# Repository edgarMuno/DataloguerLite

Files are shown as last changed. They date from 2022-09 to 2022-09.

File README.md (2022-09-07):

# DataloguerLite
Dataloguer basico que soporta sensor de temperatura SHTX, sensor de humedad con protocolo RS485 RTU, sensor de humedad con protocolo SDI-12, puerto analogico, puerto para conexion de actuador. El sistema de monitoreo se le puede configurar el intervalo de medicion, el URL de Ubidots, APN, Direccion de sensores, Numero de sensores y el tipo de sensores mediante la memoria SD. El sistema se alimenta con un panel solar y baterias, y trasmite mediante un modulo GPRS los datos a la pltaforma UBIDOTS para la vizulaizacion.

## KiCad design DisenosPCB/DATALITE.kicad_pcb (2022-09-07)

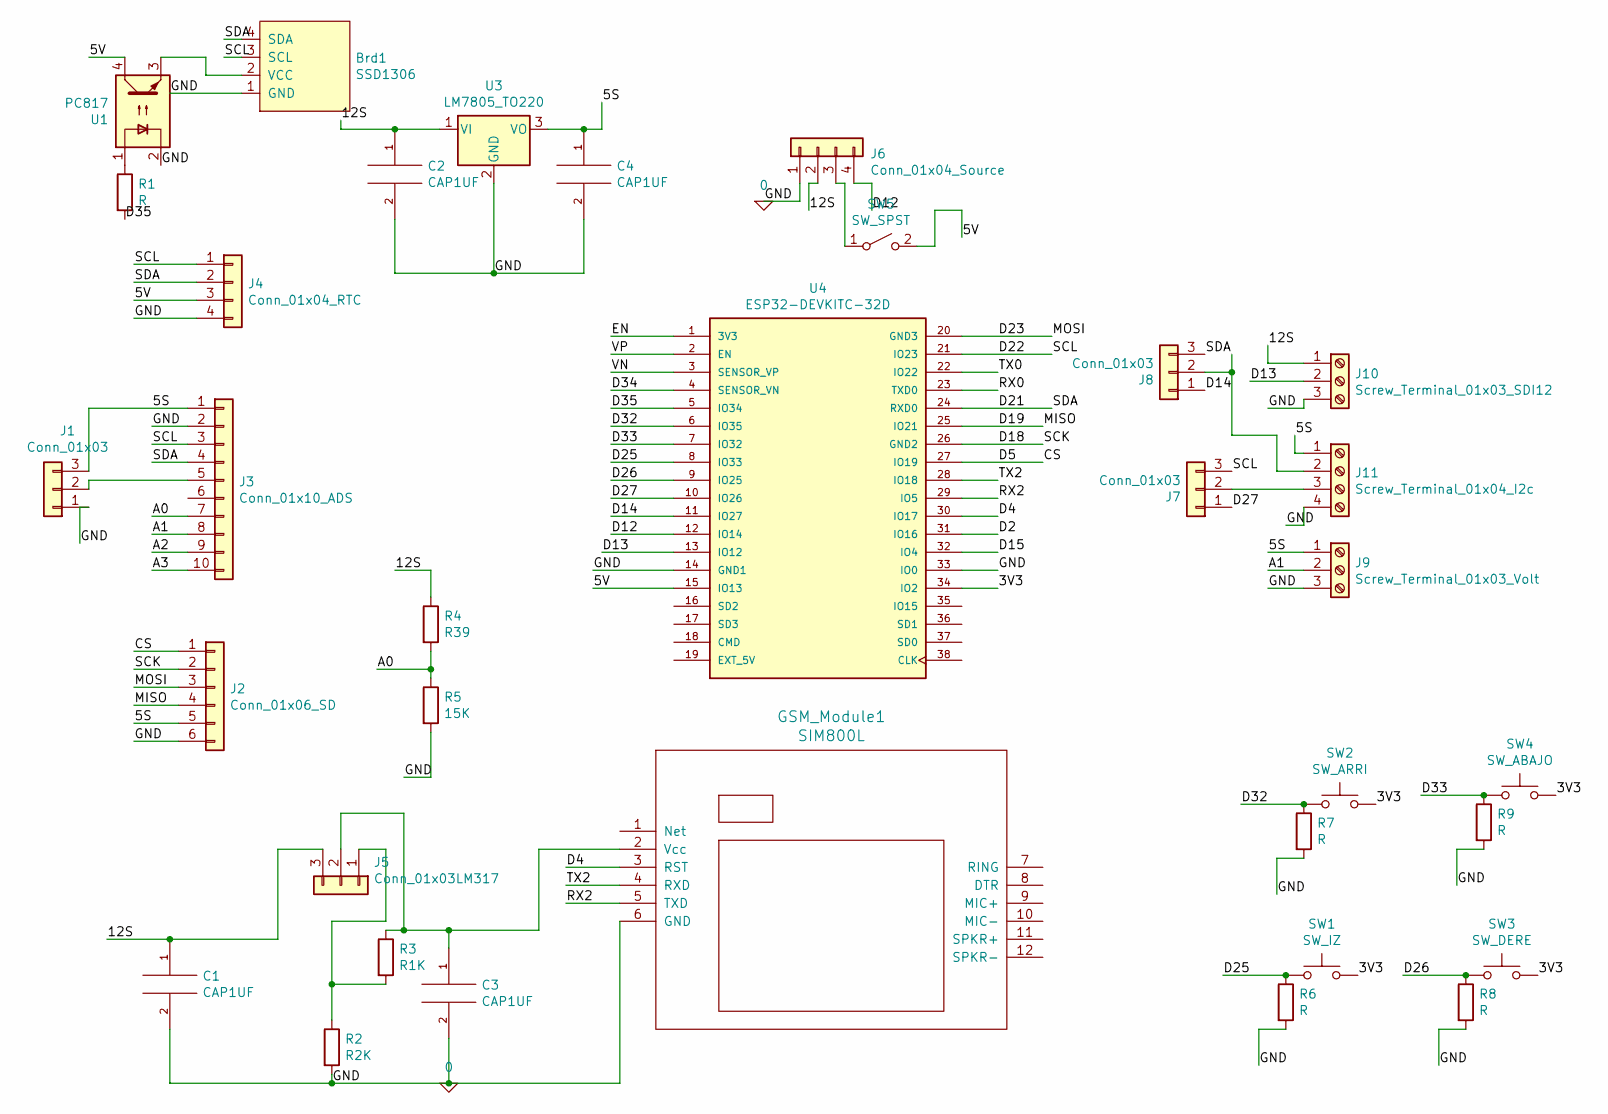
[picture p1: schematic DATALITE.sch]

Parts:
Brd1: SSD1306; 128x64OLED
C1, C2, C3, C4: CAP1UF; CP_Radial_D8.0mm_P3.50mm
GSM_Module1: SIM800L
J1, J7, J8: Conn_01x03; PinHeader_1x03_P2.54mm_Vertical
J2: Conn_01x06_SD; PinHeader_1x06_P2.54mm_Vertical
J3: Conn_01x10_ADS; PinHeader_1x10_P2.54mm_Vertical
J4: Conn_01x04_RTC; PinHeader_1x04_P2.54mm_Vertical
J5: Conn_01x03LM317; PinHeader_1x03_P2.54mm_Vertical
J6: Conn_01x04_Source; PinHeader_1x04_P2.54mm_Vertical
J9: Screw_Terminal_01x03_Volt; TerminalBlock_bornier-3_P5.08mm
J10: Screw_Terminal_01x03_SDI12; TerminalBlock_bornier-3_P5.08mm
J11: Screw_Terminal_01x04_I2c; TerminalBlock_bornier-4_P5.08mm
R1, R6, R7, R8, R9: R; R_Axial_DIN0309_L9.0mm_D3.2mm_P12.70mm_Horizontal
R2: R2K; R_Axial_DIN0309_L9.0mm_D3.2mm_P12.70mm_Horizontal
R3: R1K; R_Axial_DIN0309_L9.0mm_D3.2mm_P12.70mm_Horizontal
R4: R39; R_Axial_DIN0309_L9.0mm_D3.2mm_P12.70mm_Horizontal
R5: 15K; R_Axial_DIN0309_L9.0mm_D3.2mm_P12.70mm_Horizontal
SW1: SW_IZ; SW_PUSH_6mm_H4.3mm
SW2: SW_ARRI; SW_PUSH_6mm_H4.3mm
SW3: SW_DERE; SW_PUSH_6mm_H4.3mm
SW4: SW_ABAJO; SW_PUSH_6mm_H4.3mm
SW5: SW_SPST; SW_DIP_SPSTx01_Piano_10.8x4.1mm_W7.62mm_P2.54mm
U1: PC817; DIP-4_W7.62mm
U3: LM7805_TO220; TO-220-3_Vertical
U4: ESP32-DEVKITC-32D; MODULE_ESP32-DEVKITC-32D; PARTREV 4

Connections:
0: Brd1.1 (GND), C1.2, C2.2, C3.2, C4.2, GSM_Module1.6 (GND), J1.1, J2.6, J3.2, J4.4, J6.1, J9.3, J10.3, J11.4, R2.2, R5.2, R6.2, R7.2, R8.2, R9.2, U1.2, U3.2 (GND), U4.14 (GND1), U4.33 (IO0)
/3V3: SW1.2, SW2.2, SW3.2, SW4.2, U4.34 (IO2)
/5S: C4.1, J1.3, J2.5, J3.1, J9.1, J11.1, U3.3 (VO)
/5V: J4.3, SW5.2 (B), U1.4, U4.15 (IO13)
/12S: C1.1, C2.1, J5.3, J6.2, J10.1, R4.1, U3.1 (VI)
/A0: J3.7, R4.2, R5.1
/A1: J3.8, J9.2
/A2: J3.9
/A3: J3.10
/CS: J2.1, U4.27 (IO19)
/D2: U4.31 (IO16)
/D4: GSM_Module1.3 (RST), U4.30 (IO17)
/D12: J6.4, U4.12 (IO14)
/D13: J10.2, U4.13 (IO12)
/D14: J8.1, U4.11 (IO27)
/D15: U4.32 (IO4)
/D18: J2.2, U4.26 (GND2)
/D19: J2.4, U4.25 (IO21)
/D21: Brd1.4 (SDA), J3.4, J4.2, J8.3, U4.24 (RXD0)
/D22: Brd1.3 (SCL), J3.3, J4.1, J7.3, U4.21 (IO23)
/D23: J2.3, U4.20 (GND3)
/D25: R6.1, SW1.1, U4.8 (IO33)
/D26: R8.1, SW3.1, U4.9 (IO25)
/D27: J7.1, U4.10 (IO26)
/D32: R7.1, SW2.1, U4.6 (IO35)
/D33: R9.1, SW4.1, U4.7 (IO32)
/D34: U4.4 (SENSOR_VN)
/D35: R1.2, U4.5 (IO34)
/EN: U4.1 (3V3)
/RX0: U4.23 (TXD0)
/RX2: GSM_Module1.5 (TXD), U4.29 (IO5)
/TX0: U4.22 (IO22)
/TX2: GSM_Module1.4 (RXD), U4.28 (IO18)
/VN: U4.3 (SENSOR_VP)
/VP: U4.2 (EN)
unnamed: Brd1.2 (VCC), U1.3
unnamed: C3.1, GSM_Module1.2 (Vcc), J5.2, R3.1
unnamed: J1.2, J3.5
unnamed: J5.1, R2.1, R3.2
unnamed: J6.3, SW5.1 (A)
unnamed: J8.2, J11.2
unnamed: J7.2, J11.3
unnamed: R1.1, U1.1

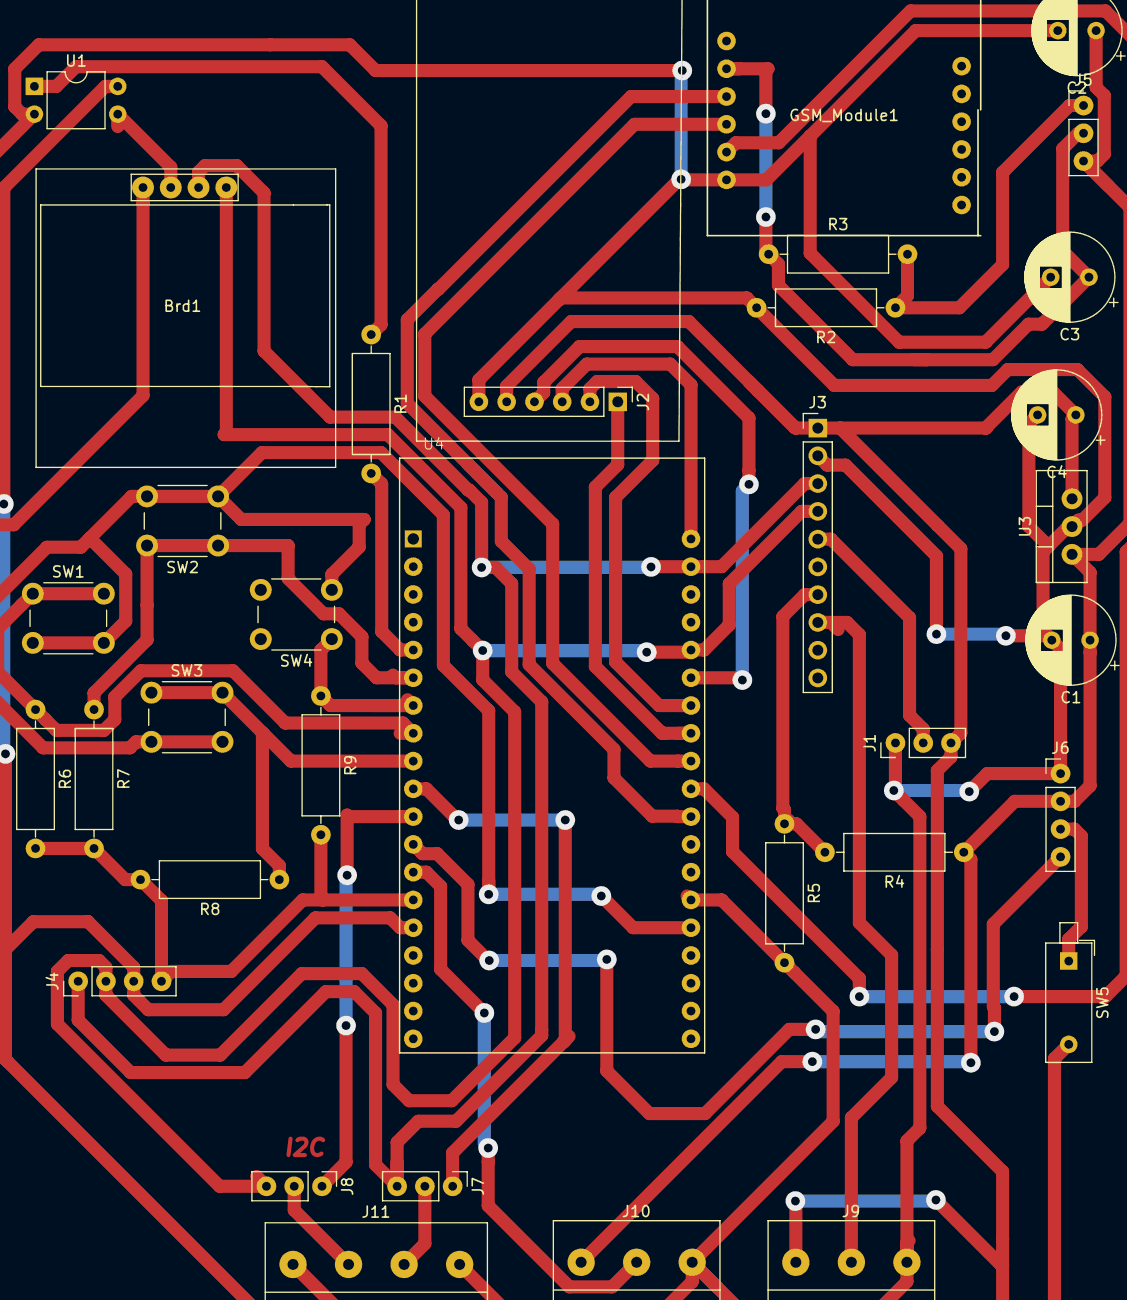
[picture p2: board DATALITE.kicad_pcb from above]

Board: 2 copper layers, 34 parts (0 on the bottom side), 33 nets.

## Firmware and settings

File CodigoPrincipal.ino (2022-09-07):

//sdi12
#include <SDI12.h>
//sd library
#include "FS.h"
#include "SD.h"

#include <SPI.h>

const String FileConfig="/config/config.txt";
//Reloj//
#include <RTClib.h>

#include "configinterval.h"
#define uS_TO_S_FACTOR 1000000ULL  /* Conversion factor for micro seconds to seconds */
#define TIME_TO_SLEEP  180        /* Time ESP32 will go to sleep (in seconds) */

RTC_DATA_ATTR int time_tot = -1;

//int time_tot = -1;
RTC_DS3231 rtc;
RTC_DATA_ATTR char interSel[1]={'2'};
String address;
 #define SD_CS 5
const uint8_t pinSwitch=12;
FormatInter FI;
//sdi12//
#define DATA_PIN 13 
SDI12 mySDI12(DATA_PIN);
String sensor_dir="2";
////humedad ambiente////
#include "Wire.h" ;// si no aparece la librería es por motivos del soft "< "
#include <SHT1x-ESP.h>
#define dataPin  14 //AMARILLO
#define clockPin 27 //AZUL
SHT1x sht1x(dataPin, clockPin);
/////////gprs//////
#include "SIM800L.h"
#define SIM800_RST_PIN 4
#define RXD2 16
#define TXD2 17
char APN[30];
SIM800L* sim800l;
String namedevice;
String token;
///////adc1/////
#include <Adafruit_ADS1015.h>
Adafruit_ADS1115 ads(0x48);
void setup() {
    
    pinMode(pinSwitch,OUTPUT);
    Serial.begin(115200);
    pinMode(2,OUTPUT);
    Serial2.begin(9600, SERIAL_8N1, RXD2, TXD2);// serial1 pines 4 y 2
    sim800l = new SIM800L((Stream *)&Serial2, SIM800_RST_PIN, 200, 500);
    ads.begin();
    if(time_tot<0){
      digitalWrite(pinSwitch,HIGH);
      digitalWrite(2,HIGH);
       if (!initRTC(false)) {
          Serial.println("RTC failed");
          return;
        }
        digitalWrite(pinSwitch,HIGH);
        delay(1000);
        SD.begin(SD_CS);  
        if (!SD.begin(SD_CS)) {
          Serial.println("falla sd");
           return;    // init failed
        }
        InitConfig();
        medir();
        InitTempo();
        digitalWrite(pinSwitch,LOW);
        digitalWrite(2,LOW);
        digitalWrite(pinSwitch,LOW);
    }else{
      if (!initRTC(false)) {
          Serial.println("RTC failed");
          return;
        }
    }
    FI.SetFormatInter(interSel);
    medir();
    esp_sleep_enable_timer_wakeup(TIME_TO_SLEEP * uS_TO_S_FACTOR);
    Serial.println("Going to sleep now");
    Serial.flush(); 
    esp_deep_sleep_start();

  //Serial.println(FI.Getnum_interval());
  
  // put your setup code here, to run once:

}
void despetad(){
  
}

void loop() {
  // put your main code here, to run repeatedly:
  delay(10000);
  //medir();
  

}

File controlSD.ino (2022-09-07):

void writeFile(fs::FS &fs, const char * path, const char * message) {
  File file = fs.open(path, FILE_WRITE);
  if(!file) {
    return;
  }
  if(file.print(message)) {
    //Serial.println("File written");
  } else {
 //   Serial.println("Write failed");
  }
  file.close();
}

String readFile(fs::FS &fs, const char * path){

    String cadena="";
    File file = fs.open(path);
    if(!file){
      //  Serial.println("Failed to open file for reading");
        return cadena;
    }

   //Serial.print("Read from file: ");
    while(file.available()){
       char cara= file.read();
       cadena=cadena+cara;
    }
    file.close();
    return cadena;
}

void appendFile(fs::FS &fs, const char * path, const char * message) {
  //Serial.printf("Appending to file: %s\n", path);

  File file = fs.open(path, FILE_APPEND);
  if(!file) {
   
    return;
  }
  if(file.print(message)) {
  } else {
  }
  file.close();
}




bool guardar(String datos){

  
    SD.begin(SD_CS);  
    if (!SD.begin(SD_CS)) {
      //Serial.println("falla sd");
      return false;    // init failed
    }

  char date_on[] = "YYYY-MM";
  char date_rec[]="DD-hh:mm";
  DateTime now = rtc.now();
  now.toString(date_on);
  
  now.toString(date_rec);
  String date[3]={};
  extraer_carga(date_on,date,"-");
  String date0=date[0]+date[1];
  String fileNa="/archivos/"+date[0]+"_"+date[1]+".csv";
  File file = SD.open(fileNa);//fileNa="/data.txt", datos"/data.txt", "Reading ID, Date, Hour, Temperature \r\n"
  if(!file) {
    char cabe[]="Fecha,Segmento 1,Segmento 2,Segmento 3,Temperatura 1,Temperatura 2, Humedad Amb.,Temperatura Amb,Bateria\n";
    writeFile(SD,fileNa.c_str(),cabe);
  }
  String datos_=String(date_rec)+","+datos+"\n";
  appendFile(SD,fileNa.c_str(),datos_.c_str());
  //Serial.println("guardado=> "+datos_);
  file.close();

}

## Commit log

2022-09-07 Add files via upload
    Funcional, con intervalos de programacion, se realiza la configuracion en la SD.
2022-09-07 Add files via upload
    Los gerbers para realizar el circuito en CNC. Los disenos PCB se realizaron en kiCAD
    [DATALITE-B_Cu.gbr, DATALITE-B_Mask.gbr, DATALITE-B_Paste.gbr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]
